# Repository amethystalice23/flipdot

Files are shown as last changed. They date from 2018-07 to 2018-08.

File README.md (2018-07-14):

# flipdot
Code, docs and drivers for the Swansea Hackspace flipdot project.

## The project
A member of Swansea Hackspace has got a hold of a bunch of old flip-dot
display boards that used to be on a bus.

With only one functional driver unit, and no manuals, we have set about
trying to reverse engineer them, and turn them into functional displays.

[The Project So Far](http://swansea.hackspace.org.uk/Main/Projects)

This repository serves to hold some of the more fluid items like Code
to drive the boards, protocol descriptions, and so on.

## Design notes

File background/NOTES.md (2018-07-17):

# Notes of observations from annotated_trace

1 Colour pin(9) can and is left high or low for long periods

2 The Enable Pins all change with each commit

3 most sequences pulse row 1 or 2 times, and column rarely
 this implies that neither counter is reset by commit

4 if row is pulsed once per cycle, column is pulse every 16th

5 commit with column high and all 4 enables high is a column reset ?
  immediately followed by a standard commit
  examples: 959500

6 curious event at 1515500  really long pulse on P0+P1 whilst pulsing
  column and commit

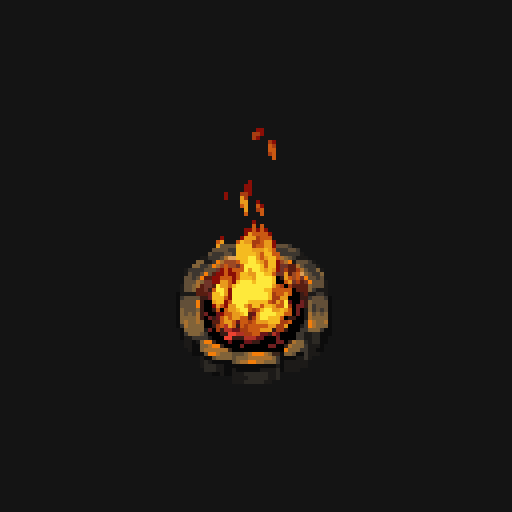
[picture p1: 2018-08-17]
web/games/gifs/fire.gif

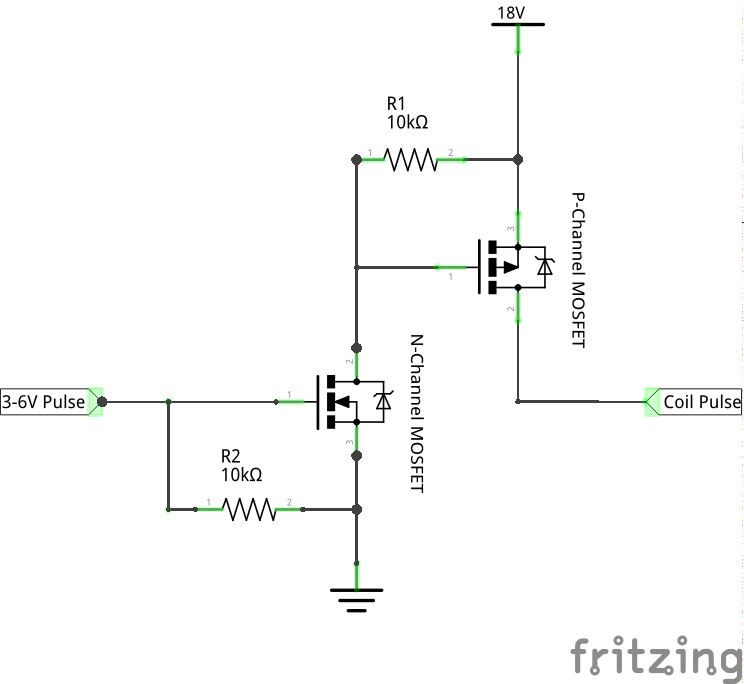
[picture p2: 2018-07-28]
background/coil_drive_schem.png

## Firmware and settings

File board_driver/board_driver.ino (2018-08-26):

/*
 * Swansea Hackspace FlipDot Driver system
 * 
 * Library Requires:
 * - Adafruit GFX Library
 * - CopyThreads
 */
 
 #include <Cth.h>
#include <Adafruit_GFX.h>
#include "FlipDot_GFX.h"


FlipDot_GFX display;

/* Driver address pins (w/ pullups) */
#define PANELADDR_0         2
#define PANELADDR_1         3
#define PANELADDR_2         4
#define PANELADDR_3         5

uint8_t read_paneladdr(void)
{
    uint8_t num = 0;

    if (digitalRead(PANELADDR_0) == HIGH) num |= 0x01;
    if (digitalRead(PANELADDR_1) == HIGH) num |= 0x02;
    if (digitalRead(PANELADDR_2) == HIGH) num |= 0x04;
    if (digitalRead(PANELADDR_3) == HIGH) num |= 0x08;
    return num;
}

/* falling rain effect */
void rain(int count, int speed)
{
    uint8_t const h = display.height();
    while (count > 0) {
        display.scrollright();
        uint8_t row = random(h);
        display.drawPixel(0, row, 1);
        display.display();
        count--;
        delay(speed);
    }
}

/* scroll some text
 * call with frame==-1 to obtain number of frames required
 * then call with frame == 0..N
 */
int scrolltext(String msg, int frame)
{
  uint8_t w = display.width();
  int twidth = (msg.length() * 6) + w;

  if (frame == -1) return twidth;

  display.clearDisplay();
  display.setCursor(w-frame,4);
  display.print(msg);
  display.display();
}

/* just plain draw text */
void show_text(String text)
{
  display.clearDisplay();
  display.setCursor(0,4);
  display.print(text);
  display.display();
#ifdef DEBUG
  Serial.print("Display text: ");
  Serial.println(text);
#endif
}

int8_t hextoi(char h)
{
    if (h >= '0' && h <= '9')
        return h - '0';
    if (h >= 'A' && h < 'F')
        return 10 + (h - 'A');
    if (h >= 'a' && h < 'f')
        return 10 + (h - 'a');
    return -1;
}

unsigned int readHex(String hex)
{
    unsigned int val = 0;
    for (uint8_t i=0; i<hex.length(); i++) {
        char h = hextoi( hex.charAt(i) );
        if (h == -1) break;
        val <<= 4;
        val |= h;
    }
    return val;
}

/* unit number of this panel driver, and its ascii hex char */
uint8_t unit = 0;
char unitc = '0';

bool ignoreLine = false;
String inbuff;

void setup() {
  /* these pins give the unit address */
  pinMode(PANELADDR_0, INPUT_PULLUP);
  pinMode(PANELADDR_1, INPUT_PULLUP);
  pinMode(PANELADDR_2, INPUT_PULLUP);
  pinMode(PANELADDR_3, INPUT_PULLUP);

  /* Serial port to receive commands */
  Serial.begin(115200);
#ifdef DEBUG
  Serial.print("\x1B""[2J");
  Serial.print("\x1B""[1;1H");
  Serial.println("FlipDot Driver");
#endif

  /* initialise the flipdot panel */
  display.begin();
  display.setRotation(0);
  display.setTextSize(1);
  display.setTextColor(WHITE);
  display.setTextWrap(false);
  display.clearDisplay();
  display.refresh();
  delay(200);
#ifdef DEBUG
  Serial.println("Initial clear");
  delay(5000);
#endif

  /* read the unit id number and display it */
  unit = read_paneladdr();
  if (unit < 10)
      unitc = '0' + unit;
  else
      unitc = 'A' + (unit - 10);

  show_text("#" + (String)unit);
#ifdef DEBUG
  Serial.println("Flipdot Unit #" + (String)unit + " = '"+(String)unitc+"'");
#endif
  delay(200);

  Scheduler.startLoop(loopSerial);
}

/* unpack a bitmap into flipdot pixels */
void write_bitmap(const char *buff)
{
    int x=0, y=0;
    uint8_t const h = display.height();
    uint8_t const w = display.width();

    if (buff[0] == 0) return;
    if (buff[1] != 'B') return;
    buff += 2;

    while (*buff != 0) {
        int8_t v = hextoi(*buff);
        /* bad character, not hex, stop */
        if (v == -1) break;
        if (x >= w) {
            x = 0;
            y++;
        }
        /* guard against overruns */
        if (y >= h) break;

        display.drawPixel(x  , y, (v&8)?WHITE:BLACK);
        display.drawPixel(x+1, y, (v&4)?WHITE:BLACK);
        display.drawPixel(x+2, y, (v&2)?WHITE:BLACK);
        display.drawPixel(x+3, y, (v&1)?WHITE:BLACK);

        x += 4;
        buff++;
    }
}
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

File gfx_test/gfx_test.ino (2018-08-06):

#include <Adafruit_GFX.h>
#include "FlipDot_GFX.h"

FlipDot_GFX display;

void setup() {
  /* debug to serial port,
     use a vt100/ansi terminal for better debug */
  Serial.begin(115200);

  Serial.println("Panel Graphics Test");
  display.begin();
  display.setRotation(0);
  display.clearDisplay();
  display.refresh();
}

/* display random circles */
void circles(int count)
{
    uint8_t const w = display.width();
    uint8_t const h = display.height();
    uint8_t const maxr = min(w, h) / 2;

    display.clearDisplay();

    while (count > 0) {
        uint8_t x = random(w);
        uint8_t y = random(h);
        uint8_t r = random(2, maxr);

        display.drawCircle(x,y,r+1,0);
        display.fillCircle(x,y,r,1);
#ifdef DEBUG
        display.refresh();
        Serial.print("\x1B[0KCircles: ");
        Serial.print(count);
        Serial.print(" ("); Serial.print(x); Serial.print(","); Serial.print(y); Serial.print(") r="); Serial.println(r);
#else
        display.display();
#endif
        delay(100);
        count--;
    }
}

void rain(int count, int speed)
{
    uint8_t const h = display.height();
    while (count > 0) {
        display.scrollright();
        uint8_t row = random(h);
        display.drawPixel(0, row, 1);
#ifdef DEBUG
        display.refresh();
        Serial.print("\x1B[0KRain: ");
        Serial.print(count);
        Serial.print(" ");
        Serial.println(row);
#else
        display.display();
#endif
        count--;
        delay(speed);
    }
}

void scrolltext(String msg, int speed)
{
  uint8_t w = display.width();
  uint8_t twidth = (msg.length() * 6) + w;
  for(uint8_t x=0;x<twidth;x++) {
      display.clearDisplay();
      display.setCursor(w-x,4);
      display.print(msg);
#ifdef DEBUG
      Serial.println("\x1B[0KText: " + msg);
      display.refresh();
#else
      display.display();
#endif
      delay(speed);
  }
}

void waggle(String msg, int speed)
{
      display.clearDisplay();
      display.setCursor(0,4);
      display.print(msg);
      display.refresh();
      delay(1000);

      for (uint8_t i=0; i<3; i++) {
          display.scrolldown();
          display.refresh();
          delay(speed);
      }
      for (uint8_t i=0; i<6; i++) {
          display.scrollup();
          display.refresh();
          delay(speed);
      }
      for (uint8_t i=0; i<3; i++) {
          display.scrolldown();
          display.refresh();
          delay(speed);
      }
}

void loop() {
  display.invert();
  display.clearDisplay();
  display.refresh();
  Serial.println("\x1B[0KText: Clear Panel");
  delay(1000);

  display.fillRect(0,0,display.width(), display.height(), WHITE);
  display.refresh();
  delay(1000);

  display.clearDisplay();
  display.drawRect(1, 2, 7, 7, BLACK);
  display.drawRect(2, 3, 5, 5, WHITE);
  display.display();
#ifdef DEBUG
  Serial.println("\x1B[0KDraw Rectangle");
  delay(1000);
  // show the full display just for the debug
  display.refresh(); 
#endif
  delay(1000);

  display.setTextSize(1);
  display.setTextColor(WHITE);
  display.setTextWrap(false);

  waggle("Hello", 200);
  delay(1000);

  scrolltext("This is Swansea Hackspace!", 100);
  delay(1000);

  display.clearDisplay();
  rain(30, 200);
  rain(30, 100);
  rain(60, 50);
  rain(60, 25);
  rain(200, 0);
  for (uint8_t i=0; i<display.width(); i++) {
      display.scrollright();
      display.display();
  }

  delay(3000);

  circles(100);
  delay(1000);
  
}

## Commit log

2018-07-14 First draft of proposed protocol
    This is a proposal for a simple protocol between the controlling
    computer and the panel driver units.
2018-07-16 Test of Adafruit_GFX layered over the flipdot panel driver
    [FlipDot_GFX.cpp, gfx_test.ino, panel.cpp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]
2018-07-17 Add Pulseview trace captured from original display controller
    Originally captured by PB
2018-07-17 Try new driver functions based on the logic trace
2018-07-17 Add some notes to the trace marking reset points and other curious events
2018-07-28 Update driver to use the logic suggested online
    Uses the logic suggested by the website
    https://github.com/themainframe/esp32-flipdot-controller
    Requires a MOSFET driver for the 18v coil pulse line as
    described by background/coil_drive_schem.png
    [coil_drive.fzz]
2018-07-28 update GFX demo to use the latest driver backend
2018-08-03 Almost working panel driver (DANGER BEWARE)
    This revision drives the pixels in a way which
    works, but only if you never stop updating and
    shifting the addressed pixel. If it pauses for more than
    a couple of seconds your panel will start to smoke and burn
    this is because it is not pulsing the 18v line and relying
    on you having drive it high manually.
    [panel.cpp, panel.h, simple_test.ino]
2018-08-03 Fix bug in differential updates
    and add nicer debug if you have a vt100/ansi terminal
    e.g. screen /dev/ttyUSB0 115200
    [FlipDot_GFX.cpp, gfx_test.ino]
2018-08-03 Add the coil power control that we need
2018-08-03 update panel driver to match simple_test
2018-08-05 Update the MOSFET coil driver with specific parts and a veroboard layout
    [coil_drive.fzz]
2018-08-06 Small fixes and panel now works
    [FlipDot_GFX.cpp, gfx_test.ino]
2018-08-20 Add outline of final panel driver code
2018-08-25 Improve debug mode, fix up mistakes that reveals
    [FlipDot_GFX.cpp, board_driver.ino]
2018-08-26 Add lightweight threading to improve serial read speed, GFX and flipdot driving happens in the background. No locking or queueing, commands issued too quickly could trample on each other.
    [FlipDot_GFX.cpp, board_driver.ino]
